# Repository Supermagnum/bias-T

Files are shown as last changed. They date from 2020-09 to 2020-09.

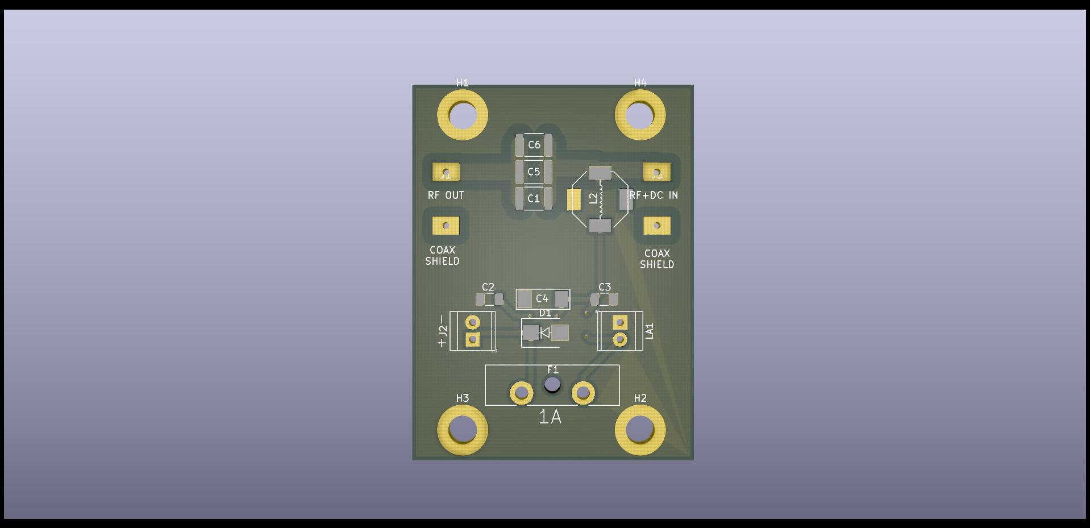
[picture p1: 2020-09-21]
injector-smd/bias-t-injector-smd.jpg

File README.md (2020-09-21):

# bias-T
Two small  DC bias injector/extractor PCB's.
They makes it possible to power relays or other equipment without a additional separate DC cable.
DC voltages up to 60 volts is OK.

The injector board has a holder for a 1A ATO fuse. All DC copper traces should handle 1.5 A.
The RF traces are 2.5 mm wide.

The reason for the dual inductors is that in the event RF is present on the coax cable shield, the 100 uH inductor should stop it. 
All capacitors is ceramic SMD. The diode protects against reverse polarity and voltage spikes generated by relay coils.
The PCB boards measures 42X56mm.

The components should handle 1000 W RF from 160 meters to and including two meters.
That is 1.8 MHz to 145 MHz. 

IMPORTANT! 

That kind of RF power is not advised on FR4 based circuit boards!
RT/duroid® Laminates or similar products is required.
Please read: https://rushpcb.com/manufacturing-rf-and-high-frequency-boards/

scematic diagram:
https://github.com/Supermagnum/bias-T/blob/master/scema.png

For those who are lazy, the pcb boards + components is avaible here ( 100 W should be OK ):

Injector:
https://aisler.net/p/JQQXAEPC

Extractor:
https://aisler.net/p/MLCWOMDY

Dimensions:
https://github.com/Supermagnum/bias-T/blob/master/size.png

For those who wants the gerber files, and BOM's:

extractor:
https://github.com/Supermagnum/bias-T/tree/master/extractor-smd

Injector:
https://github.com/Supermagnum/bias-T/tree/master/injector-smd

Source article:
http://www.ad5x.com/images/Articles/RemoteDC%20RevA.pdf

73!

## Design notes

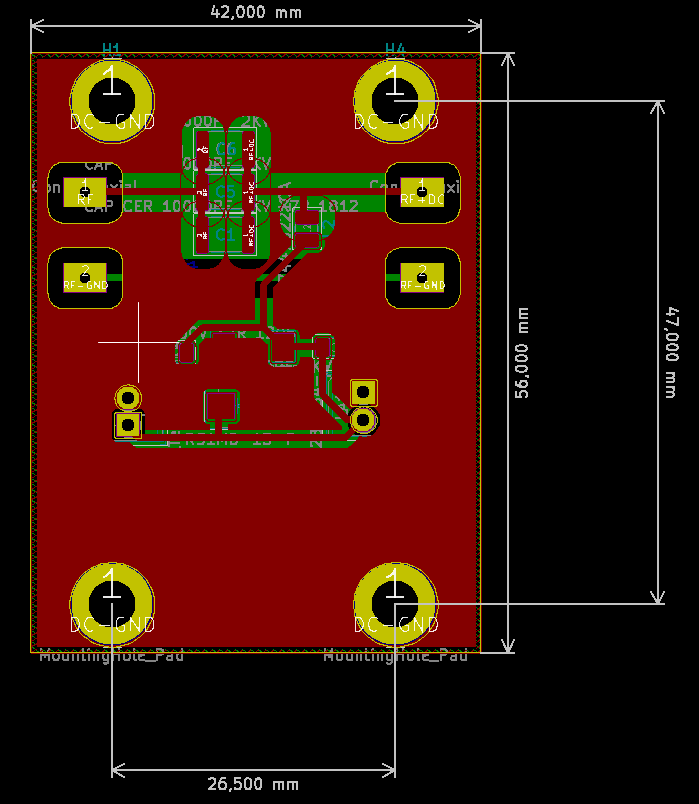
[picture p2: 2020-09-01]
size.png

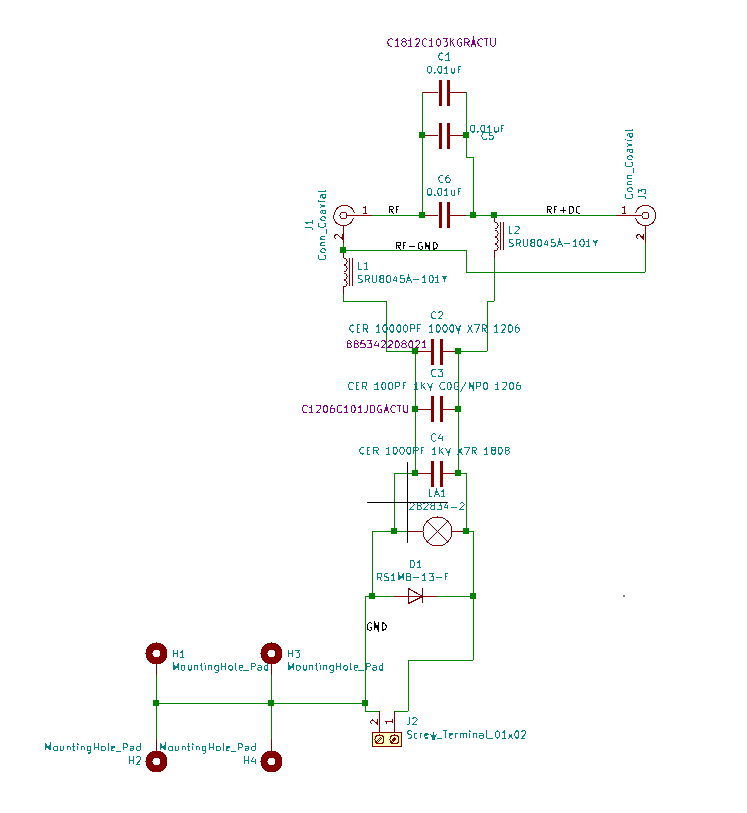
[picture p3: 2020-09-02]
scema.png

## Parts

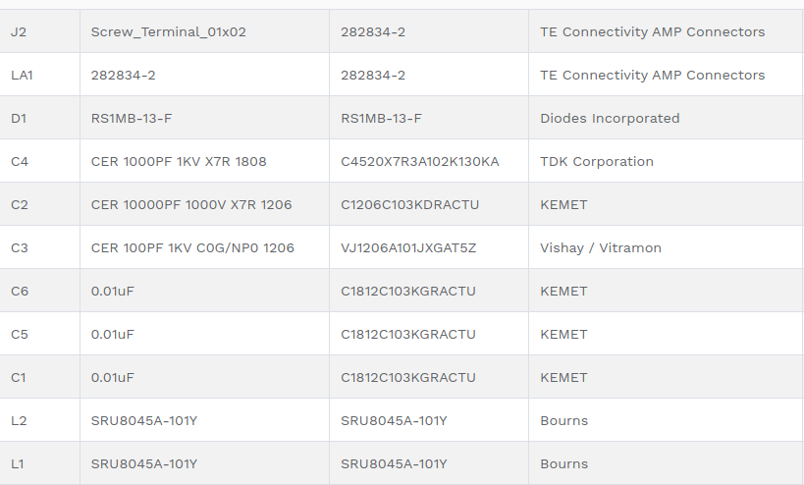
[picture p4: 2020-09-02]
extractor-smd/extractor-BOM.png

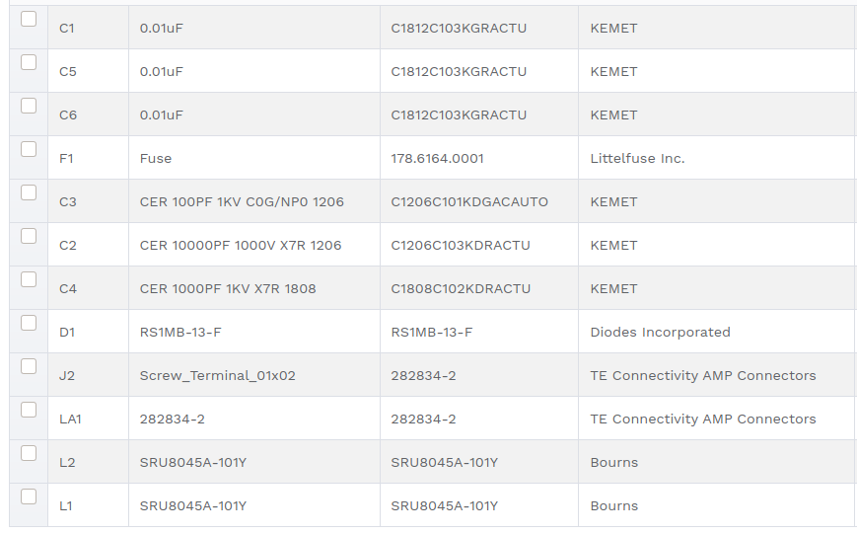
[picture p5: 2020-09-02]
injector-smd/BOM.png

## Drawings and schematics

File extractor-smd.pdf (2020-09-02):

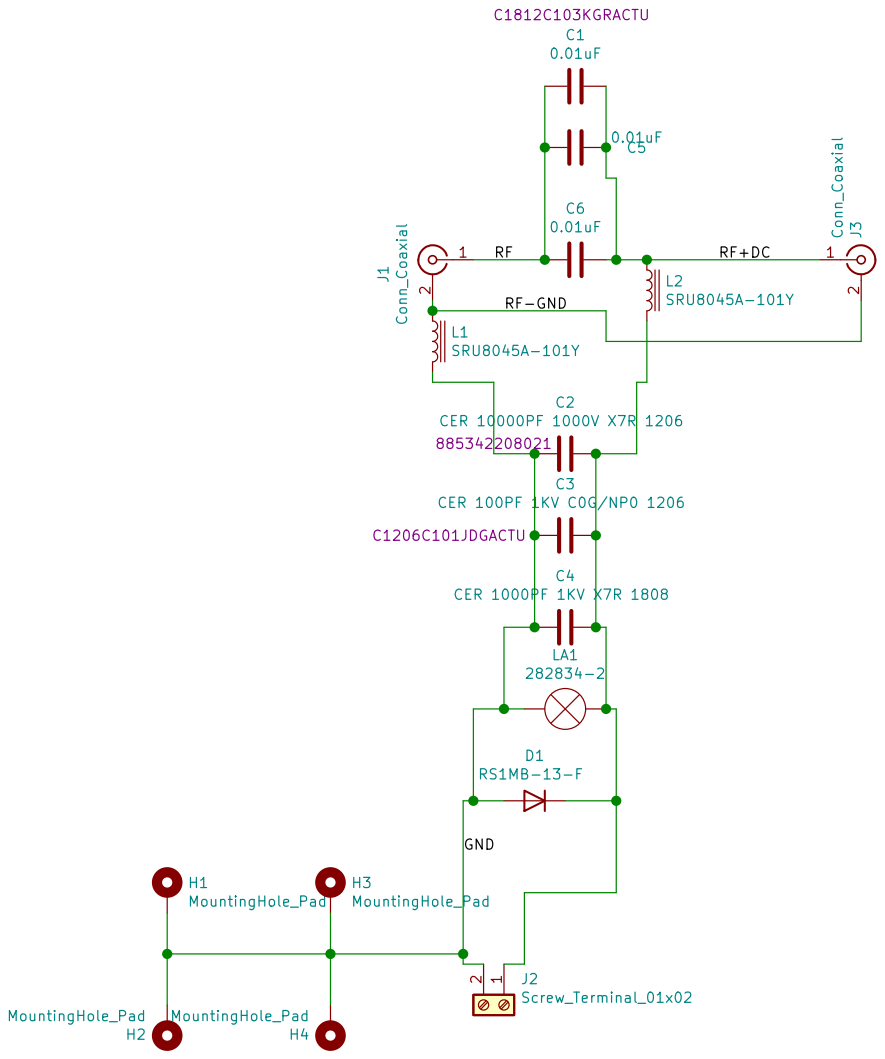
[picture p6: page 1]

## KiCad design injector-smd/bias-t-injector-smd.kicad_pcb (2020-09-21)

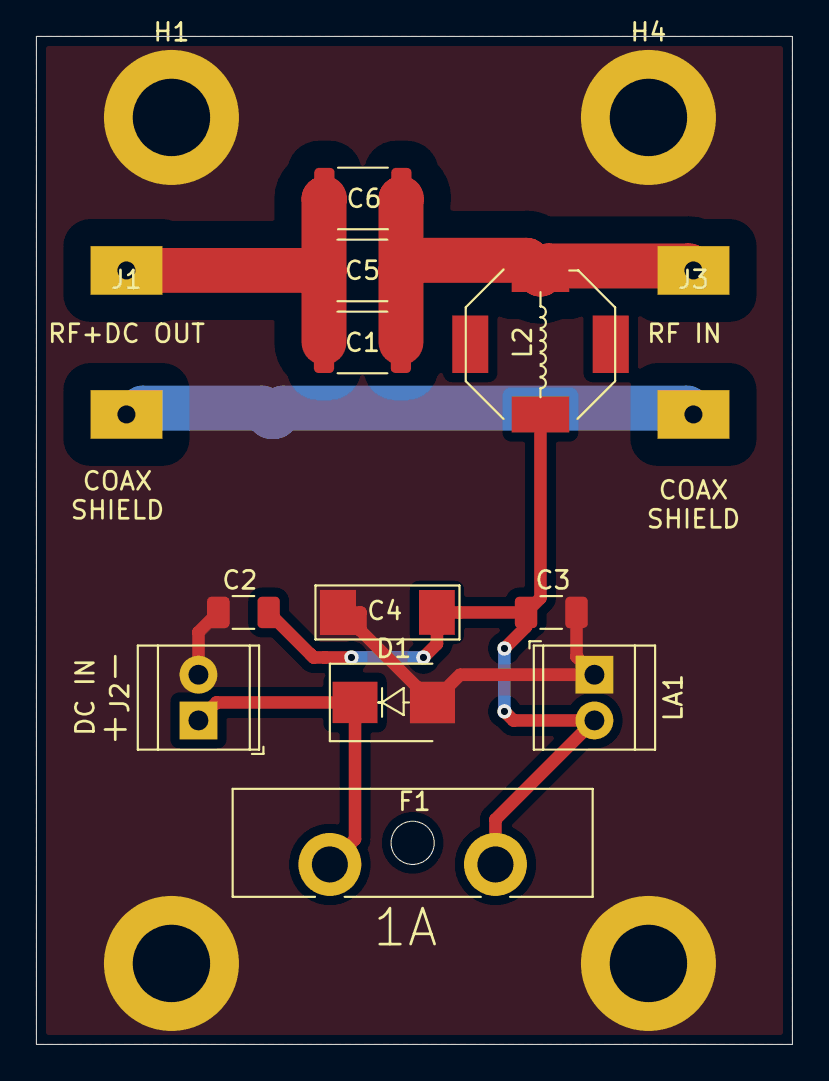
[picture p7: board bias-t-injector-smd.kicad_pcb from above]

Board: 2 copper layers, 42.0 x 56.0 mm, 18 parts (1 on the bottom side), 6 nets.

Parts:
C1, C5, C6: 0.01uF; C_1812_4532Metric
C2: CER 10000PF 1000V X7R 1206; C_1206_3216Metric
C3: CER 100PF 1KV C0G/NP0 1206; C_1206_3216Metric
C4: CER 1000PF 1KV X7R 1808; C_1808_4520_Metric
D1: RS1MB-13-F; D_SMB
F1: Fuse; Fuseholder_Blade_ATO_Littelfuse_Pudenz_2_Pin
H1, H2, H3, H4: MountingHole_Pad; MountingHole_4.3mm_M4_DIN965_Pad
J1, J3: Conn_Coaxial; SO-239-pads
J2: Screw_Terminal_01x02; TerminalBlock_TE_282834-2_1x02_P2.54mm_Horizontal
L1, L2: SRU8045A-101Y; L_Bourns-SRU8045A-101Y_8.0x8.0mm
LA1: 282834-2; TerminalBlock_TE_282834-2_1x02_P2.54mm_Horizontal

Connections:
/GND: C2.2, C3.2, C4.2, D1.2, H1.1, H2.1, H3.1, H4.1, J2.2, L1.2, LA1.1
/RF: C1.2, C5.2, C6.2, J1.1
/RF+DC: C1.1, C5.1, C6.1, J3.1, L2.1
/RF-GND: J1.2, J3.2, L1.1
unnamed: C2.1, C3.1, C4.1, F1.1, L2.2, LA1.2
unnamed: D1.1, F1.2, J2.1

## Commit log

2020-09-01 added BOM and gerbers.
    [bias-t-extractor-smd-B_Adhes.gbr, bias-t-extractor-smd-B_Cu.gbr, bias-t-extractor-smd-B_Mask.gbr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]
2020-09-02 updated files and BOM's .
    [bias-t-extractor-smd-B_Adhes.gbr, bias-t-extractor-smd-B_Cu.gbr, bias-t-extractor-smd-B_Mask.gbr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]
2020-09-21 Add files via upload
    Updated RF paths to 2.5mm with
    [bias-t-extractor-smd-B_Adhes.gbr, bias-t-extractor-smd-B_Cu.gbr, bias-t-extractor-smd-B_Mask.gbr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]
2020-09-21 Add files via upload
    Updated RF paths to 2.5mm with.
    [bias-t-injector-smd-B_Adhes.gbr, bias-t-injector-smd-B_Cu.gbr, bias-t-injector-smd-B_Mask.gbr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]
2020-09-21 Update README.md
    added with of traces.
